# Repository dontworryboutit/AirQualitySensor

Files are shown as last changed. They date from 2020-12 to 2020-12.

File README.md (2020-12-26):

# Air Quality Sensor

[Trello board for project](https://trello.com/b/QzJ9ahUh/air-quality-sensor)

## Components

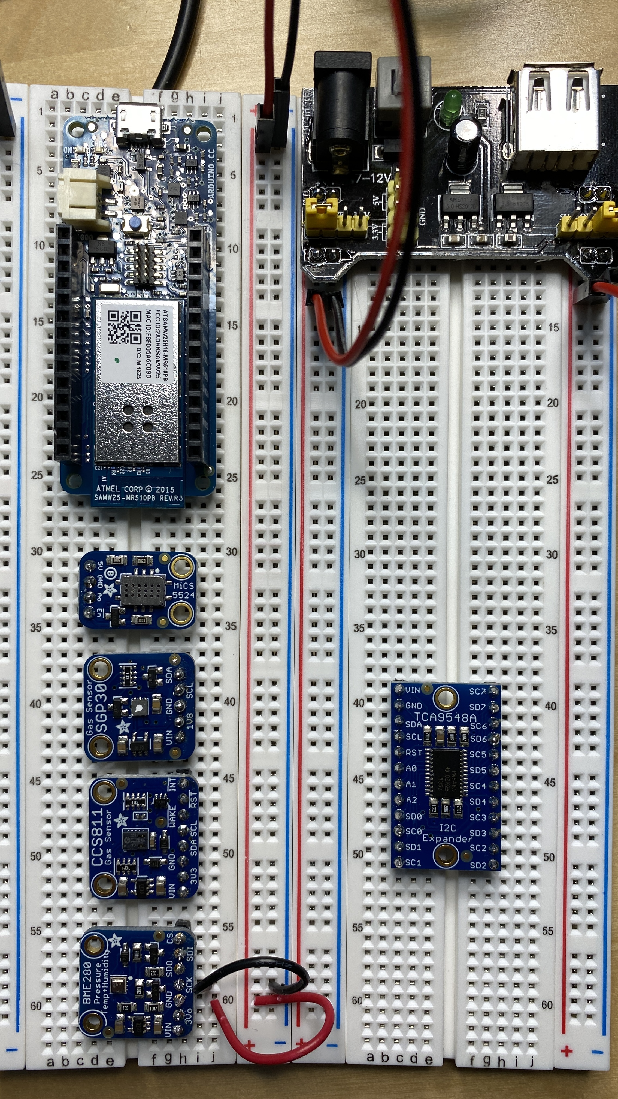
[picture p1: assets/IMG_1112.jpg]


### Microcontroller

* Arduino MKR1000
  * [Product page](https://store.arduino.cc/usa/arduino-mkr1000)
  * [diagrams](https://content.arduino.cc/assets/Pinout-MKR1000_latest.pdf)
  * [Arduino Getting Started Guide](https://www.arduino.cc/en/Guide/MKR1000/)
  * [Adding another wire interface](https://www.arduino.cc/en/Tutorial/SamdSercom/#create-a-new-wire-instance)
  * [wifi module overview](https://www.arduino.cc/en/Reference/WiFi101)

### Integrated Circuits

##### MICS 5524 - Carbon Monoxide, Alcohol and VOC Gas Sensor

Sensor is sensitive to several gases but can't distinguish between which gas.

There is a burn in time for proper calibration that is required for the sensor
to work properly.

  * [Product page](https://www.adafruit.com/product/3199)
  * [Details](https://learn.adafruit.com/adafruit-mics5524-gas-sensor-breakout)
  * [manufacturer usage details](https://www.sgxsensortech.com/content/uploads/2014/08/AN-0172-SGX-Metal-Oxide-Gas-Sensors-V1.pdf)

Does not include voltage regulator and requires a level shifter to read the analog output pin on the MKR1000

| specification | units |
| ----- | ---- |
| Input voltage  | 5v |
| Analog out pin voltage | 5v |
| current draw | 35 mA |

#### SGP30 - Gas Sensor

  * [Product page](https://www.adafruit.com/product/3709)
  * [Detailed arduino usage](https://learn.adafruit.com/adafruit-sgp30-gas-tvoc-eco2-mox-sensor/arduino-code)
  
VOC and eCO2 sensor

Uses i2c communication SCL and SDA can use 3v or 5v logic

Includes a voltage regulator

| specification | units |
| ----- | ---- |
| Input voltage  | 3v or 5v |
| Logic pin voltage | 3v or 5v |

#### CCS811 - Gas Sensor

VOC and eCO2 Sensor

Measures eCO2 and TVOC. Can detect Alcohols, Aldehydes, Ketones, Organic Acids, Amines, Aliphatic and Aromatic Hydrocarbons.
Requires calibration

  * [Product page](https://www.adafruit.com/product/3566)
  * [Pinout](https://www.adafruit.com/product/3566)
  * [Detailed arduino usage](https://learn.adafruit.com/adafruit-ccs811-air-quality-sensor/arduino-wiring-test)
    
Includes voltage regulator

| specification | units |
| ----- | ---- |
| Input voltage  | 3v or 5v |
| Logic pin voltage | 3v or 5v |

#### BME280 - Pressure, temp, humidity
  * [Product page](https://www.adafruit.com/product/2652)
  * [Details and usage](https://learn.adafruit.com/adafruit-bme280-humidity-barometric-pressure-temperature-sensor-breakout/pinouts)
  * [detailed arduino usage](https://learn.adafruit.com/adafruit-tca9548a-1-to-8-i2c-multiplexer-breakout/wiring-and-test)
  
 temperature, barometric pressure and humidity sensor 

Includes voltage regulator

| specification | units |
| ----- | ---- |
| Input voltage  | 3v or 5v |
| Logic pin voltage | 3v or 5v |

#### PMS5003 - Digital Particle Concentration Laser Sensor

  * [Product page](https://www.adafruit.com/product/3686)
  * [Manufacturers manual](https://cdn-shop.adafruit.com/product-files/3686/plantower-pms5003-manual_v2-3.pdf)
  * [Adafruit guide](https://learn.adafruit.com/pm25-air-quality-sensor)
  
PM2.5 Air Quality Sensor

Without breakout board

| specification | units |
| ----- | ---- |
| Input voltage  | 5v |
| Logic pin voltage | 3.3v |

#### TCA9548A

i2c multiplexer

  * [Product page](https://www.adafruit.com/product/2717)
  * [Details and usage](https://learn.adafruit.com/adafruit-tca9548a-1-to-8-i2c-multiplexer-breakout/overview)
  * [detailed arduino usage](https://learn.adafruit.com/adafruit-tca9548a-1-to-8-i2c-multiplexer-breakout/wiring-and-test)

Includes voltage regulator

| specification | units |
| ----- | ---- |
| Input voltage  | 3v or 5v |
| Logic pin voltage | 3v or 5v |

## Development

### Arduino CLI overview

## Potentially useful links

* [Adafruit IoT Environmental Sensor](https://learn.adafruit.com/remote-iot-environmental-sensor)

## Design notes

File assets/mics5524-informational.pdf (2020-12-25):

MiCS5524 Gas Sensor

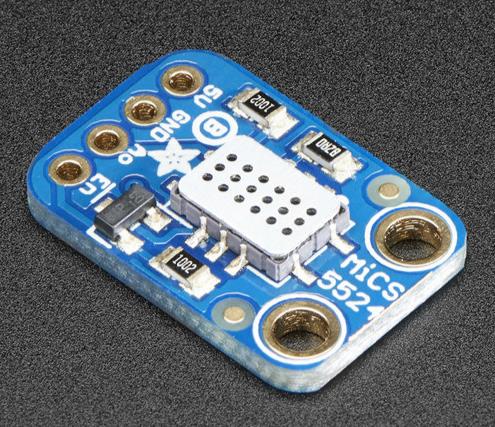
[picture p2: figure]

The MiCS5524 sensor is used to detect CO (1 to 1000ppm), NH3 (1 to 500ppm), Ethanol (10 to 500ppm), H2 (1 to 1000ppm), and methane/propane/ iso-butane (>1000ppm). However, it cannot tell the analytes apart. It is useful for detecting CO and natural gas leaks in an indoor setting. It is also suitable for breath checking and early fire detection.¹

How does the MiCS5524 work?

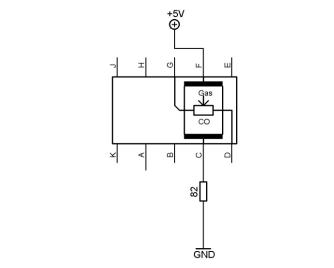
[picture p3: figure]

The MiCS5524 sensor is comprised of a silicon gas sensor with a micro machined diaphragm with an embedded heating resistor. The sensing layer is on top of this unit. The sensor is put together using MEMS (microelectromechanical systems) technology.²
This means
that the heating and sensing elements are applied by thin film fabrication. The elements work

Figure 1: MiCS5524 sensor

Figure 2: MiCS5524 circuit diagram like a MOS (metal oxide semiconductor). MOS sensors work by sensing the change in resistance when gas is present versus clean/fresh air.³

Connecting the MiCS5524

Solder the pins to the sensor before connecting to the raspberry pi.

In order to connect the MiCS5524 sensor to the Raspberry Pi, two other sensors are needed. A level converter is needed to take the 5V output signal to a 3.3V signal and an A/D converter to be able to read the signal in digital form. It is necessary to step the voltage down because a raspberry pi can only read signals at 3.3V without potential for damage. The A/D converter changes the analog signal to a digital signal in or order to calculate the concentration of gas from the signal instead of just a detection.

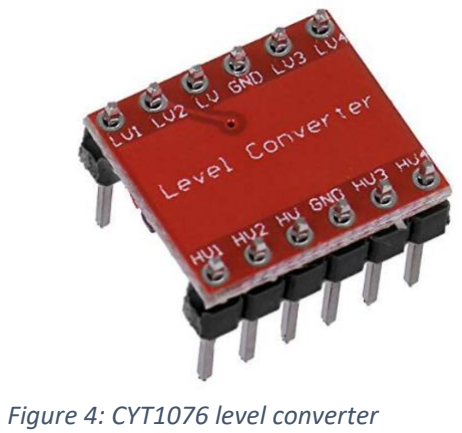
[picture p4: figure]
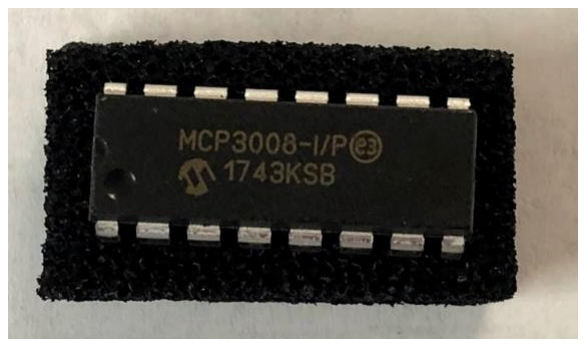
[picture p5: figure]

The sensor was connected to the raspberry pi as follows:⁴

MCP3008

Pin 16 (VDD) connects to your positive rail
Pin 15 (VREF) connects to your positive rail
Pin 14 (AGND) connects to your ground rail
Pin 13 (CLK) connects to SCLK on your Pi cobbler Pin 12(DOUT) connects to MISO on your Pi cobbler Pin 11(DIN) connects to MOSI on your Pi cobbler Pin 10 (CS) connects to CE0 on your Pi cobbler Pin 9(DGND) connects to your ground rail.

CYT1076 Red level converter

LV to Pi 3.3V Positive Rail HV to Pi 5V Positive Rail
HV side GND to GND on Pi
LV side GND to GND on Pi
LV1 to Channel 0 on MCP3008
Figure 3: MCP3008 ADC converter | Figure 4: CYT1076 level converter

MiCS5524

5V to 5V on raspberry pi

GND to GND on raspberry pi

A0 to HV1 on CYT1076

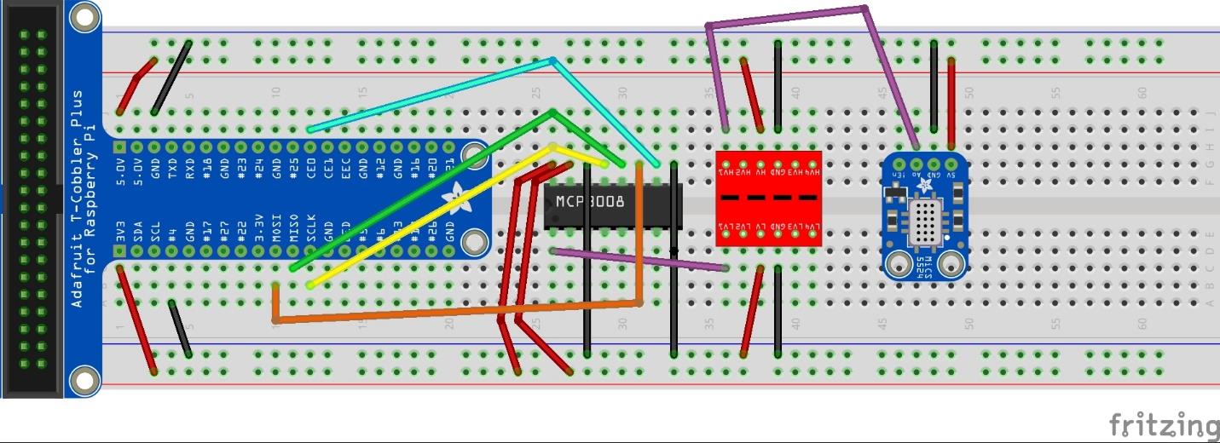
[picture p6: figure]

Coding the MiCS5524

Run the following code in the Thonny IDE.⁴

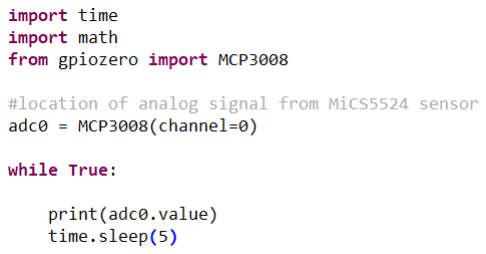
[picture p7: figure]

The ADC signal increases in the presence of CO, Ammonia, Ethanol, Methane, Propane, and Iso-Butane.

Figure 5: Raspberry Pi hookup for MiCS5524

References

(1) Overview | Adafruit MiCS5524 CO / Alcohol / VOC Gas Sensor Breakout | Adafruit
Learning System https://learn.adafruit.com/adafruit-mics5524-gas-sensorbreakout/overview (accessed Mar 20, 2019).
(2) Downloads | Adafruit MiCS5524 CO / Alcohol / VOC Gas Sensor Breakout | Adafruit
Learning System https://learn.adafruit.com/adafruit-mics5524-gas-sensorbreakout/downloads (accessed Mar 20, 2019).
(3) Metal Oxide Gas Sensing Material and MEMS Process | Sensors Magazine
/components/metal-oxide-gas-sensing-material-and-mems-process (accessed Mar 20, 2019).
(4) Usage | Adafruit MiCS5524 CO / Alcohol / VOC Gas Sensor Breakout | Adafruit Learning
System https://learn.adafruit.com/adafruit-mics5524-gas-sensor-breakout/usage (accessed Mar 20, 2019).

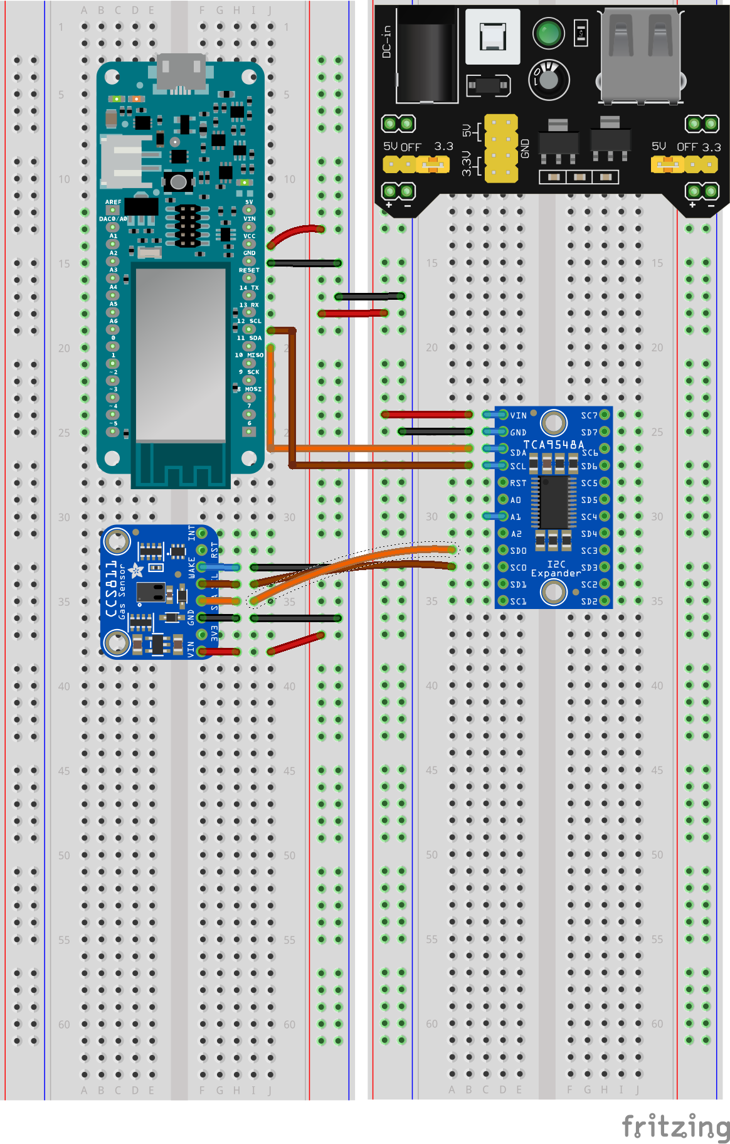
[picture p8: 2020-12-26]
layout/CCS811_bb.png

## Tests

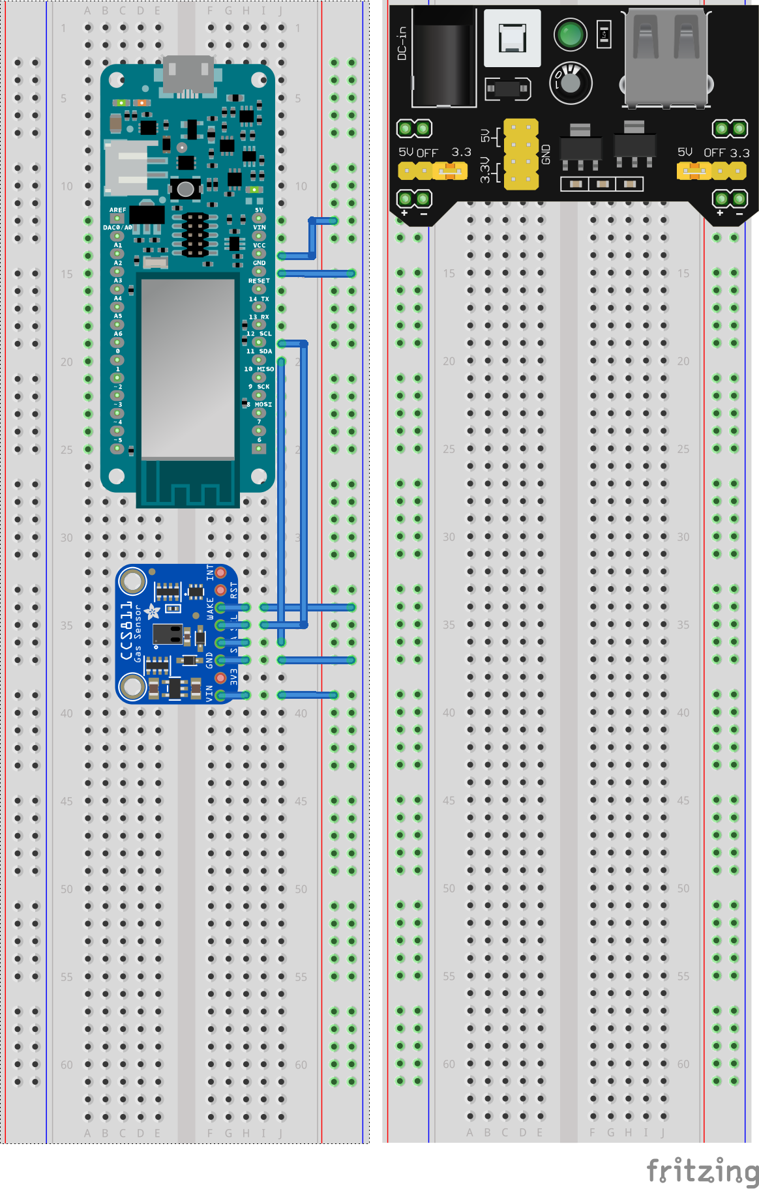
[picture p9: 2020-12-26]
layout/CCS811-test_bb.png

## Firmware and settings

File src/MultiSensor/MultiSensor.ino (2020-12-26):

#include <Wire.h>
#include <Adafruit_GFX.h>
#include "Adafruit_CCS811.h"
#include "Adafruit_SGP30.h"
#include "Adafruit_BME280.h"
#include "Adafruit_EPD.h"


// Declare the i2c address for the TCA
#define TCAADDR 0x70

// Define pinout for the eink friend
#define EPD_CS      7
#define EPD_DC      6
#define SRAM_CS     5
#define EPD_RESET   4 // can set to -1 and share with microcontroller Reset!
#define EPD_BUSY    3 // can set to -1 to not use a pin (will wait a fixed delay)

Adafruit_CCS811 ccs;
Adafruit_SGP30 sgp;



Adafruit_BME280 bme; // use I2C interface
Adafruit_Sensor *bme_temp = bme.getTemperatureSensor();
Adafruit_Sensor *bme_pressure = bme.getPressureSensor();
Adafruit_Sensor *bme_humidity = bme.getHumiditySensor();


// Declare eink display
#define COLOR1 EPD_BLACK
#define COLOR2 EPD_RED

Adafruit_IL0373 display(212, 104, EPD_DC, EPD_RESET, EPD_CS, SRAM_CS, EPD_BUSY);
#define FLEXIBLE_213


void tcaselect(uint8_t i) {
  if (i > 7) return;

  Wire.beginTransmission(TCAADDR);
  Wire.write(1 << i);
  Wire.endTransmission();
}

/* return absolute humidity [mg/m^3] with approximation formula
* @param temperature [°C]
* @param humidity [%RH]
*/
uint32_t getAbsoluteHumidity(float temperature, float humidity) {
    // approximation formula from Sensirion SGP30 Driver Integration chapter 3.15
    const float absoluteHumidity = 216.7f * ((humidity / 100.0f) * 6.112f * exp((17.62f * temperature) / (243.12f + temperature)) / (273.15f + temperature)); // [g/m^3]
    const uint32_t absoluteHumidityScaled = static_cast<uint32_t>(1000.0f * absoluteHumidity); // [mg/m^3]
    return absoluteHumidityScaled;
}

void testdrawtext(char *text, uint16_t color) {
  display.setCursor(0, 0);
  display.setTextColor(color);
  display.setTextWrap(true);
  display.print(text);
}

void displayOnMessage() {
  display.setRotation(0);

  // large block of text
  display.clearBuffer();
  display.setTextWrap(true);

  display.setCursor(10, 10);
  display.setTextSize(5);
  display.setTextColor(EPD_BLACK);
  display.print("Hello!");

  display.display();
}



void setup() {
//   while (!Serial);
  delay(1000);


  // init eink display
  Serial.println("Setting up display");
  display.begin();

#if defined(FLEXIBLE_213) || defined(FLEXIBLE_290)
  // The flexible displays have different buffers and invert settings!
  display.setBlackBuffer(1, false);
  display.setColorBuffer(1, false);
#endif

  // large block of text
  displayOnMessage();


  Wire.begin();
  Serial.begin(115200);

  Serial.println("CCS811 and SGP30 integrated");

  // Init Serial1 for PMS5003
  // sensor baud rate is 9600
  Serial1.begin(9600);

  // Initialize CCS811
  tcaselect(0);
  if(!ccs.begin()){
    Serial.println("Failed to start CCS811 sensor! Please check your wiring.");
    while(1);
  }

  // Wait for the sensor to be ready
  while(!ccs.available());

  // Initialize SGP30
  tcaselect(1);
  if (! sgp.begin()){
    Serial.println("Sensor SGP30 not found :(");
    Serial.println("Failed to start SGP30 sensor! Please check your wiring.");
    while (1);
  }
  Serial.print("Found SGP30 serial #");
  Serial.print(sgp.serialnumber[0], HEX);
  Serial.print(sgp.serialnumber[1], HEX);
  Serial.println(sgp.serialnumber[2], HEX);

  // If you have a baseline measurement from before you can assign it to start, to 'self-calibrate'
  //sgp.setIAQBaseline(0x8E68, 0x8F41);  // Will vary for each sensor!

  // Initialize BME280
  tcaselect(2);
  if (!bme.begin()) {
    Serial.println(F("Could not find a valid BME280 sensor, check wiring!"));
    Serial.println("Failed to start SGP30 sensor! Please check your wiring.");
    while (1) delay(10);
  }
  bme_temp->printSensorDetails();
  bme_pressure->printSensorDetails();
  bme_humidity->printSensorDetails();


}

void readCCS811data() {
  tcaselect(0);

  uint16_t current_eCO2, current_TVOC;




  Serial.println("CCS811:  ");
  if(ccs.available()){
    if(!ccs.readData()){
      current_eCO2 = ccs.geteCO2();
      current_TVOC = ccs.getTVOC();
      Serial.print("CO2: ");
      Serial.print(current_eCO2);
      Serial.print("ppm, TVOC: ");
      Serial.println(current_TVOC);
    }
    else{
      Serial.println("ERROR!");
      while(1);
    }
  }
  display.println("CCS811:  ");
  display.print("CO2: ");
  display.print(current_eCO2);
  display.print("     ");
  display.print("TVOC: ");
  display.println(current_TVOC);
  display.println("");
  delay(500);
}

int counter = 0;

void readSGP30data() {
  tcaselect(1);
  // If you have a temperature / humidity sensor, you can set the absolute humidity to enable the humditiy compensation for the air quality signals
  //float temperature = 22.1; // [°C]
  //float humidity = 45.2; // [%RH]
  //sgp.setHumidity(getAbsoluteHumidity(temperature, humidity));

  Serial.print("SGP30:   ");
  if (! sgp.IAQmeasure()) {
    Serial.println("Measurement failed");
    return;
  }

  Serial.print("TVOC "); Serial.print(sgp.TVOC); Serial.print(" ppb\t");
  Serial.print("eCO2 "); Serial.print(sgp.eCO2); Serial.println(" ppm");

  Serial.print("SGP30:   ");
  if (! sgp.IAQmeasureRaw()) {
    Serial.println("Raw Measurement failed");
    return;
  }
  Serial.print("Raw H2 "); Serial.print(sgp.rawH2); Serial.print(" \t");
  Serial.print("Raw Ethanol "); Serial.print(sgp.rawEthanol); Serial.println("");

  delay(1000);


  counter++;
  if (counter == 30) {
    counter = 0;

    uint16_t TVOC_base, eCO2_base;
    if (! sgp.getIAQBaseline(&eCO2_base, &TVOC_base)) {
	  Serial.print("SGP30:   ");
      Serial.println("Failed to get baseline readings");
      return;
    }
	Serial.print("SGP30:   ");
    Serial.print("****Baseline values: eCO2: 0x"); Serial.print(eCO2_base, HEX);
    Serial.print(" & TVOC: 0x"); Serial.println(TVOC_base, HEX);
  }
  display.println("SGP30:   ");
  display.print("TVOC "); display.print(sgp.TVOC); display.print(" ppb\t");
  display.print("eCO2 "); display.print(sgp.eCO2); display.println(" ppm");
  display.print("Raw H2 "); display.print(sgp.rawH2); display.print(" \t");
  display.print("Raw Ethanol "); display.print(sgp.rawEthanol); display.println("");
  display.println();
}

void readBME260data() {
  tcaselect(2);
  sensors_event_t temp_event, pressure_event, humidity_event;
  bme_temp->getEvent(&temp_event);
  bme_pressure->getEvent(&pressure_event);
  bme_humidity->getEvent(&humidity_event);

  Serial.print("BME280:  ");
  Serial.print(F("Temperature = "));
  Serial.print(temp_event.temperature);
  Serial.println(" *C");

  Serial.print("BME280:  ");
  Serial.print(F("Humidity = "));
  Serial.print(humidity_event.relative_humidity);
  Serial.println(" %");

  Serial.print("BME280:  ");
  Serial.print(F("Pressure = "));
  Serial.print(pressure_event.pressure);
  Serial.println(" hPa");


  display.println("BME280:  ");
  display.print(F("Temp = "));
  display.print(temp_event.temperature);
  display.println(" *C");

  display.print(F("Humidity = "));
  display.print(humidity_event.relative_humidity);
  display.println(" %");

  display.print(F("Pressure = "));
  display.print(pressure_event.pressure);
  display.println(" hPa");
  display.println();

  delay(1000);
}

struct pms5003data {
  uint16_t framelen;
  uint16_t pm10_standard, pm25_standard, pm100_standard;
  uint16_t pm10_env, pm25_env, pm100_env;
  uint16_t particles_03um, particles_05um, particles_10um, particles_25um, particles_50um, particles_100um;
  uint16_t unused;
  uint16_t checksum;
};

struct pms5003data data;

boolean readPMSdata(Stream *s) {
  if (! s->available()) {
    return false;
  }

  // Read a byte at a time until we get to the special '0x42' start-byte
  if (s->peek() != 0x42) {
    s->read();
    return false;
  }

  // Now read all 32 bytes
  if (s->available() < 32) {
    return false;
  }

  uint8_t buffer[32];
  uint16_t sum = 0;
  s->readBytes(buffer, 32);

  // get checksum ready
  for (uint8_t i=0; i<30; i++) {
    sum += buffer[i];
  }

  /* debugging
  for (uint8_t i=2; i<32; i++) {
    Serial.print("0x"); Serial.print(buffer[i], HEX); Serial.print(", ");
  }
  Serial.println();
  */

  // The data comes in endian'd, this solves it so it works on all platforms
  uint16_t buffer_u16[15];
  for (uint8_t i=0; i<15; i++) {
    buffer_u16[i] = buffer[2 + i*2 + 1];
    buffer_u16[i] += (buffer[2 + i*2] << 8);
  }

  // put it into a nice struct :)
  memcpy((void *)&data, (void *)buffer_u16, 30);

  if (sum != data.checksum) {
    Serial.println("Checksum failure");
    return false;
  }
  // success!
  return true;
}

void readPMS5003data() {
  if (readPMSdata(&Serial1)) {
    // reading data was successful!
    Serial.println();
    Serial.println("-----------------------------------");
    Serial.println("Concentration Units (standard)");
    Serial.print("PM 1.0: "); Serial.print(data.pm10_standard);
    Serial.print("\t\tPM 2.5: "); Serial.print(data.pm25_standard);
    Serial.print("\t\tPM 10: "); Serial.println(data.pm100_standard);
    Serial.println("---------------------------------------");
    Serial.println("Concentration Units (environmental)");
    Serial.print("PM 1.0: "); Serial.print(data.pm10_env);
    Serial.print("\t\tPM 2.5: "); Serial.print(data.pm25_env);
    Serial.print("\t\tPM 10: "); Serial.println(data.pm100_env);
    Serial.println("---------------------------------------");
    Serial.print("Particles > 0.3um / 0.1L air:"); Serial.println(data.particles_03um);
    Serial.print("Particles > 0.5um / 0.1L air:"); Serial.println(data.particles_05um);
    Serial.print("Particles > 1.0um / 0.1L air:"); Serial.println(data.particles_10um);
    Serial.print("Particles > 2.5um / 0.1L air:"); Serial.println(data.particles_25um);
    Serial.print("Particles > 5.0um / 0.1L air:"); Serial.println(data.particles_50um);
    Serial.print("Particles > 10.0 um / 0.1L air:"); Serial.println(data.particles_100um);
    Serial.println("---------------------------------------");
  } else {
    Serial.println('Skipping PMS5003 reading...');
  }
}

void displayPMS5003data() {
    display.println("Concentration Units (standard)");
    display.print("PM 1.0: "); display.print(data.pm10_standard);
    display.print("\t\tPM 2.5: "); display.print(data.pm25_standard);
    display.print("\t\tPM 10: "); display.println(data.pm100_standard);
    display.println("------------------------------");
    display.println("Concentration Units (environmental)");
    display.print("PM 1.0: "); display.print(data.pm10_env);
    display.print("\t\tPM 2.5: "); display.print(data.pm25_env);
    display.print("\t\tPM 10: "); display.println(data.pm100_env);
    display.println("----------------------------");
    display.print("Par. > 0.3um / 0.1L air:"); display.println(data.particles_03um);
    display.print("Par. > 0.5um / 0.1L air:"); display.println(data.particles_05um);
    display.print("Par. > 1.0um / 0.1L air:"); display.println(data.particles_10um);
    display.print("Par. > 2.5um / 0.1L air:"); display.println(data.particles_25um);
    display.print("Par. > 5.0um / 0.1L air:"); display.println(data.particles_50um);
    display.print("Par. > 10.0um / 0.1L air:"); display.println(data.particles_100um);
    display.println("---------------------------------------");
}

void prepDisplay() {
  display.clearBuffer();
  // large block of text

  display.setCursor(0, 5);
  display.setTextSize(1);
  display.setTextColor(EPD_BLACK);
}

void writeDisplay() {
  display.display();
  delay(5000);
}


void loop() {
  prepDisplay();
  readBME260data();
  readCCS811data();
  readSGP30data();
  writeDisplay();

  prepDisplay();
  readPMS5003data();
  displayPMS5003data();
  writeDisplay();

}

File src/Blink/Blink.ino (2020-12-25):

/*
  Blink

  Turns an LED on for one second, then off for one second, repeatedly.

  Most Arduinos have an on-board LED you can control. On the UNO, MEGA and ZERO
  it is attached to digital pin 13, on MKR1000 on pin 6. LED_BUILTIN is set to
  the correct LED pin independent of which board is used.
  If you want to know what pin the on-board LED is connected to on your Arduino
  model, check the Technical Specs of your board at:
  https://www.arduino.cc/en/Main/Products

  modified 8 May 2014
  by Scott Fitzgerald
  modified 2 Sep 2016
  by Arturo Guadalupi
  modified 8 Sep 2016
  by Colby Newman

  This example code is in the public domain.

  http://www.arduino.cc/en/Tutorial/Blink
*/

// the setup function runs once when you press reset or power the board
void setup() {
  // initialize digital pin LED_BUILTIN as an output.
  pinMode(LED_BUILTIN, OUTPUT);
}

// the loop function runs over and over again forever
void loop() {
  digitalWrite(LED_BUILTIN, HIGH);   // turn the LED on (HIGH is the voltage level)
  delay(1000);                       // wait for a second
  digitalWrite(LED_BUILTIN, LOW);    // turn the LED off by making the voltage LOW
  delay(1000);                       // wait for a second


   digitalWrite(LED_BUILTIN, HIGH);   // turn the LED on (HIGH is the voltage level)
  delay(1000);                       // wait for a second
  digitalWrite(LED_BUILTIN, LOW);    // turn the LED off by making the voltage LOW
  delay(1000);     

  delay(5000); 
}

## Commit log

2020-12-25 Added Makefile for helping with arduino cli upload process
2020-12-25 Added wiring diagram for SGP30
    [SGP30-test.fzz]
2020-12-25 Working setup with wiring and sgp30test to read data
2020-12-26 Working layout a test for i2c communication for the ccs811
    [CCS811-test.fzz]
2020-12-26 Using the i2c multiplexer to handle reading from the CCS811
    [CCS811.fzz]
2020-12-26 Save! Working multi sensor with enk display
2020-12-26 Integrated PMS5003 into sensor
